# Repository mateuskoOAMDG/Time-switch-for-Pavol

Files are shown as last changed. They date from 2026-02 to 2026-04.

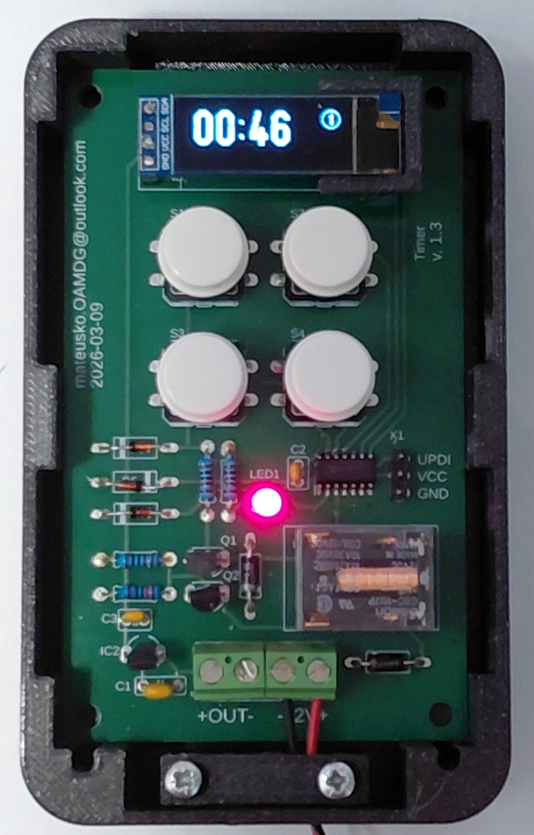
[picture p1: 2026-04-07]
images/Timer12V assembled.png

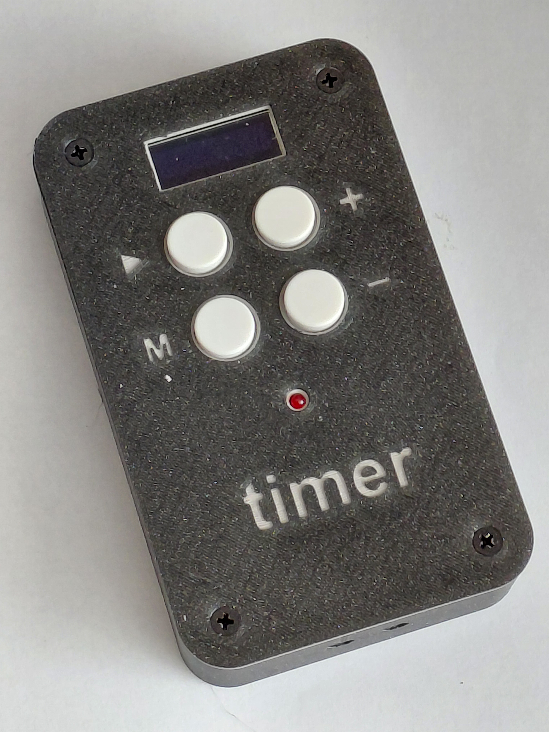
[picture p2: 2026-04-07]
images/Timer-foto1.jpg

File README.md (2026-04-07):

# Timer12V

Simple  timer switch for cars. Switches on the power supply to the heated mat for a set time. The time can be set and stored in one of four memory slots. It is controlled by four buttons and has an OLED display.

For details, see the Wiki (in Slovak) https://github.com/mateuskoOAMDG/Time-switch-for-Pavol/wiki





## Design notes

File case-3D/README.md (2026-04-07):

# List of files for 3D printing
This folder contains all the files for printing the box for the Timer
- 1x **case-top.stl** : The top part of the box should be printed in two colors. The bottom layers (0.5 mm) is black; the rest is gray PETG. 0.25 mm nozzle
- 1x **case-bottom.stl** : The bottom part of the box, printed in black PETG, 0.4 mm nozzle
- 1x **spacer-for-display.stl** : Spacer pad for the display. It is attached to the PCB.
- 1x **top-cable-holder.stl** : The top part of the cable holder. It is secured with two screws into the plastic.
- 4x **button-spacer.stl** : Fretboard pad. It slides onto the button, and the fretboard is then mounted onto it.

*.f3d files are Fusion360 files. You can edit individual parts before printing.

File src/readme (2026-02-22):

This is a sketch for Arduino. There are two files in the Timer directory: .ino and .h. Both must be downloaded and saved in the Timer sketch folder.

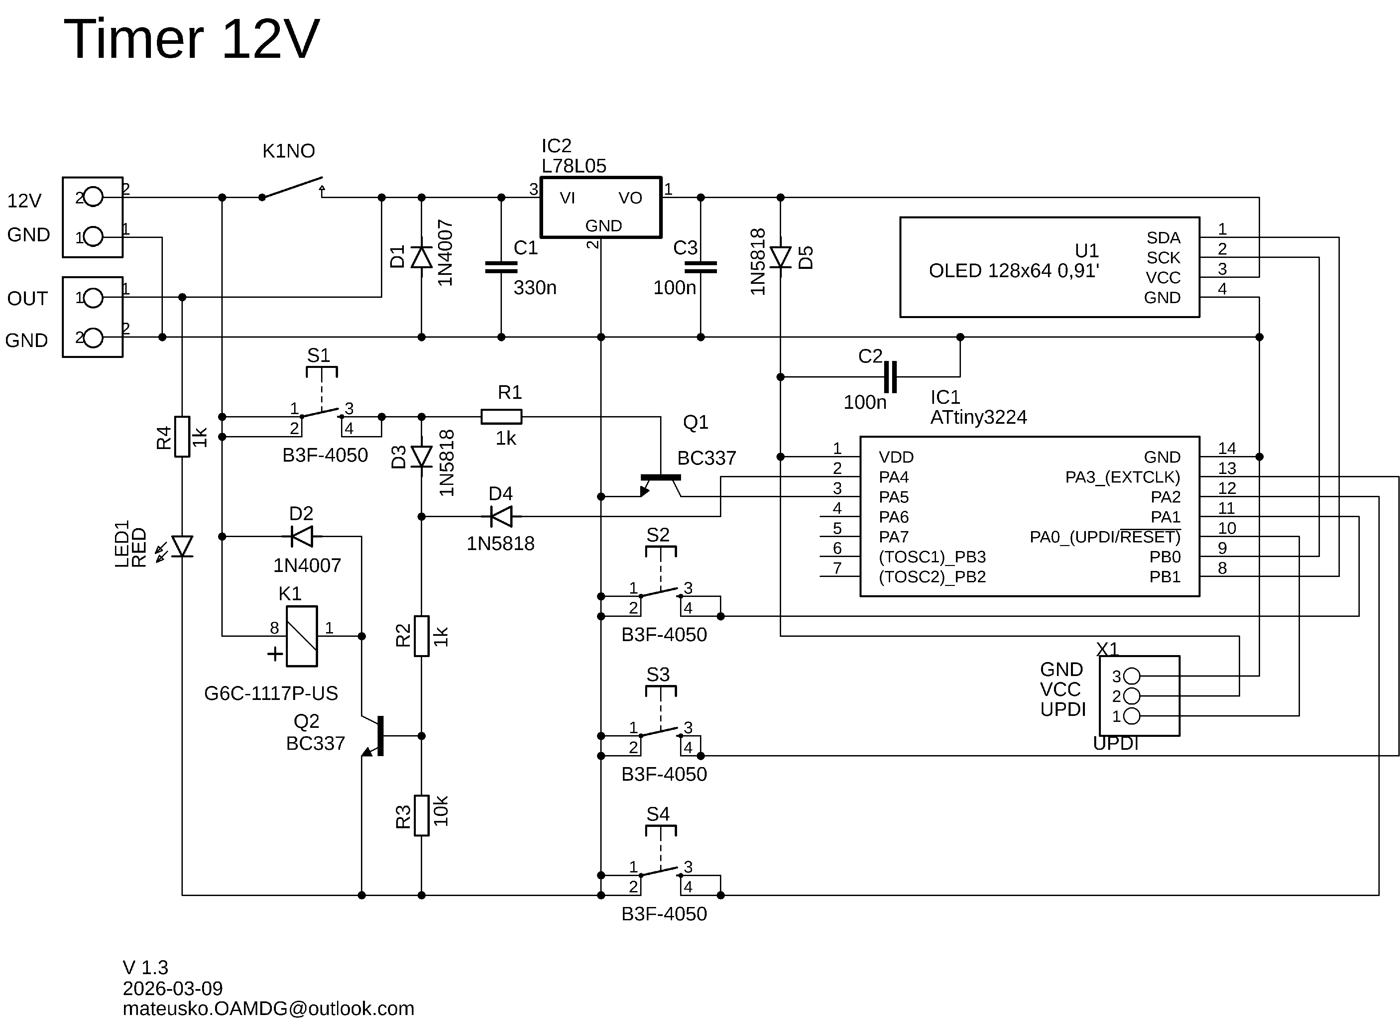
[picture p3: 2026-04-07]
images/Schematics-1.3.png

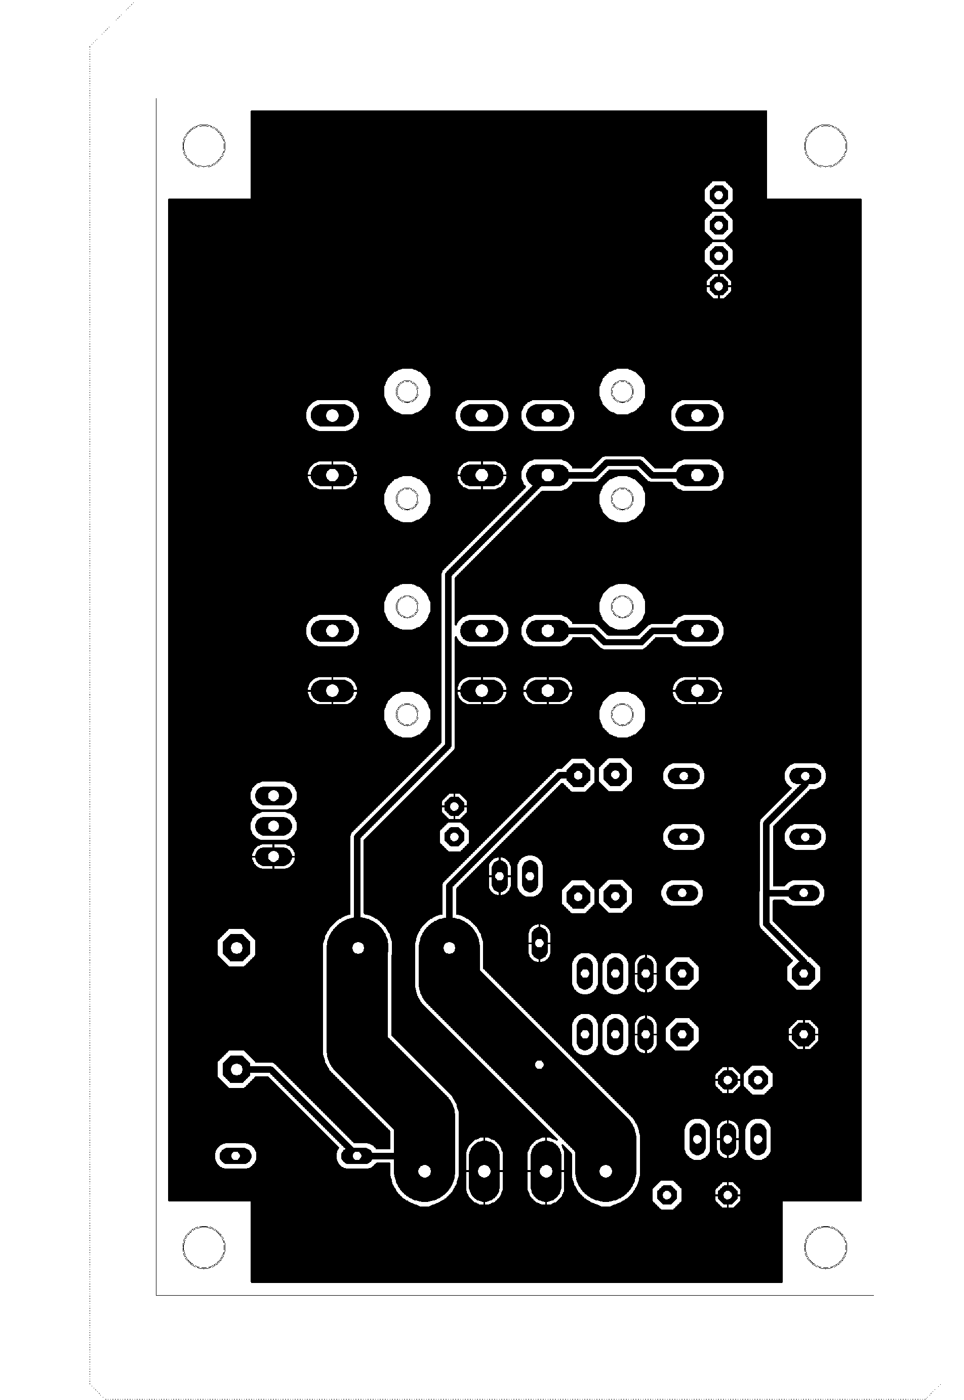
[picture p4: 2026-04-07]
images/PCB-Bottom-1.3.png

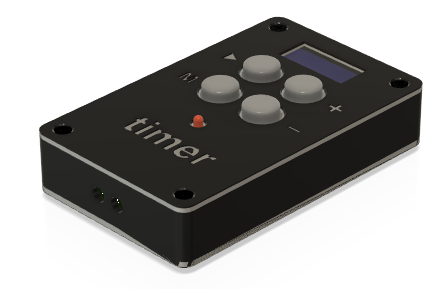
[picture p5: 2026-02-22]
images/case-thumb.png

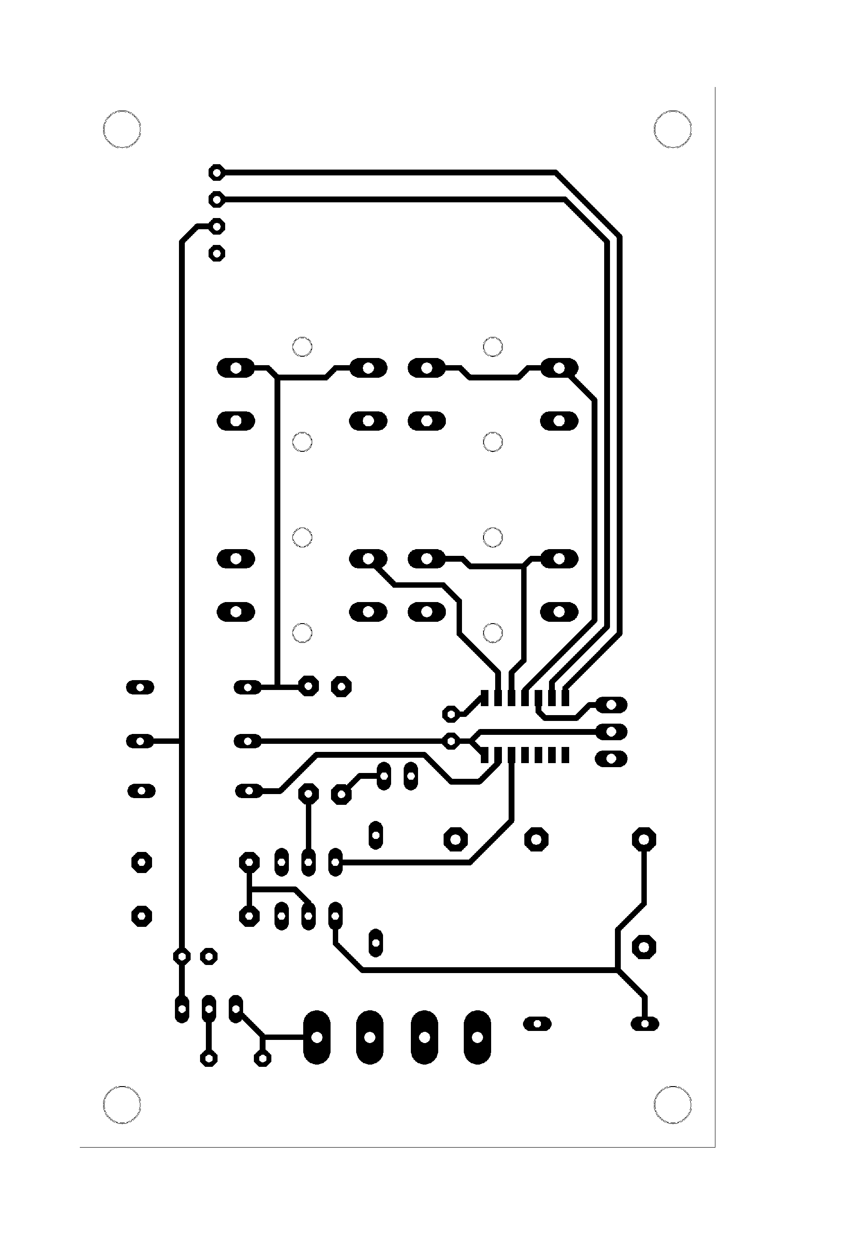
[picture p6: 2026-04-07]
images/PCB-Top-1.3.png

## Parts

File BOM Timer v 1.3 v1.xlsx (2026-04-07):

Name | Timer v 1.3 v1
Exported by | mattheusko
Time of Export | 7. 4. 2026 12:21
Reference Designators | Quantity | Value | Package
 | 1 |  | Board
12V | 1 | TERMINAL_2X_5MM_10A |  | terminal
C1 | 1 | 330n |  | ceramic capacitor
C2, C3 | 2 | 100n |  | ceramic capacitor
D1, D2 | 2 | 1N4007 |  | diode
D3, D4, D5 | 3 | 1N5818 |  | schottky diode
IC1 | 1 | ATtiny3224 | SOIC14 | MCU
IC2 | 1 | L78L05 | TO92 | stabilizer 5V
K1 | 1 | G6C-1117P-US |  | relay
LED1 | 1 | LED red 3mm |  | led
Q1, Q2 | 2 | BC337 | TO92 | transistor NPN
R1, R2, R4 | 3 | 1k | 0207/10 | resistor
R3 | 1 | 10k | 0207/10 | resistor
S1, S2, S3, S4 | 4 | B3F-4050 |  | switch TACT 12mm
U1 | 1 | OLED 128x64 0,91' |  | OLED display I2C, 0,91'
X1 | 1 | UPDI | 1X03 | pin strip; 3 pins
X2 | 1 | TERMINAL_2X_5MM_10A |  | terminal

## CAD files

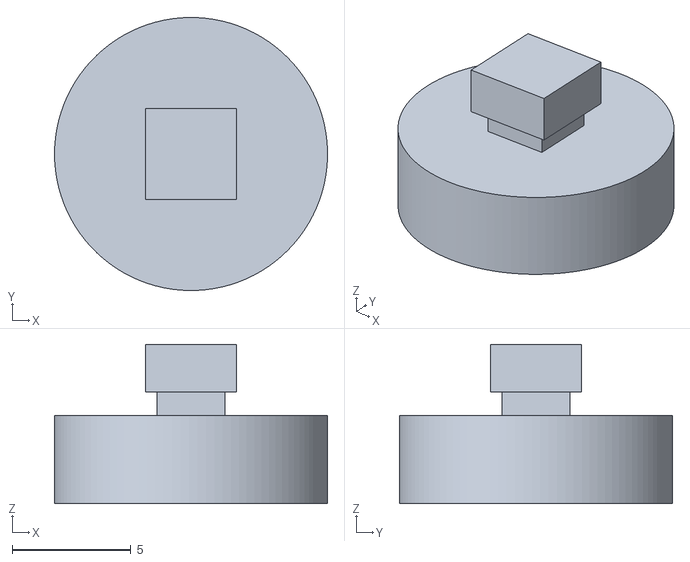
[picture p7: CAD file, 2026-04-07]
case-3D/button-spacer.stl
11.5 x 11.5 x 6.70

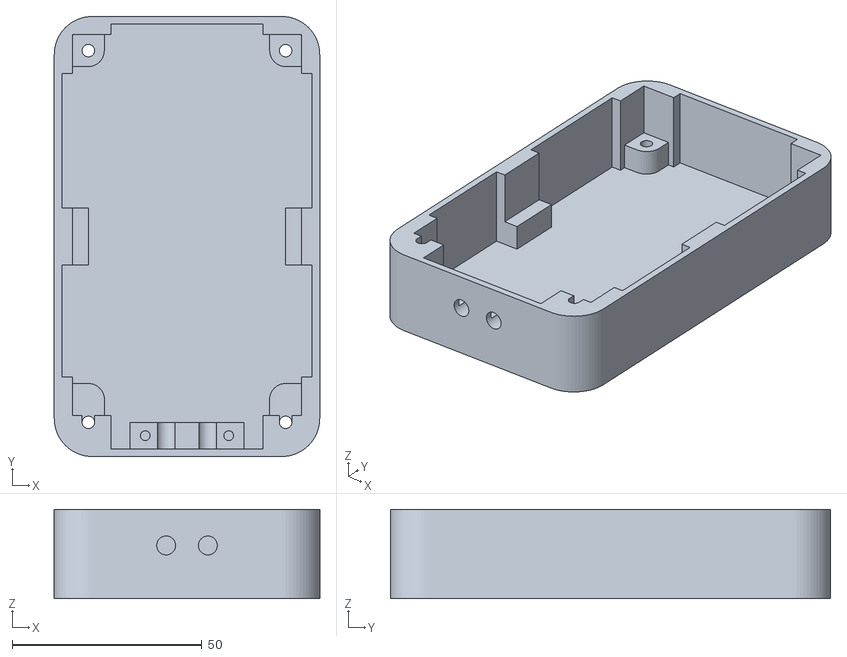
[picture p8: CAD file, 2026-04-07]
case-3D/case-bottom.stl
70.0 x 116.0 x 23.5

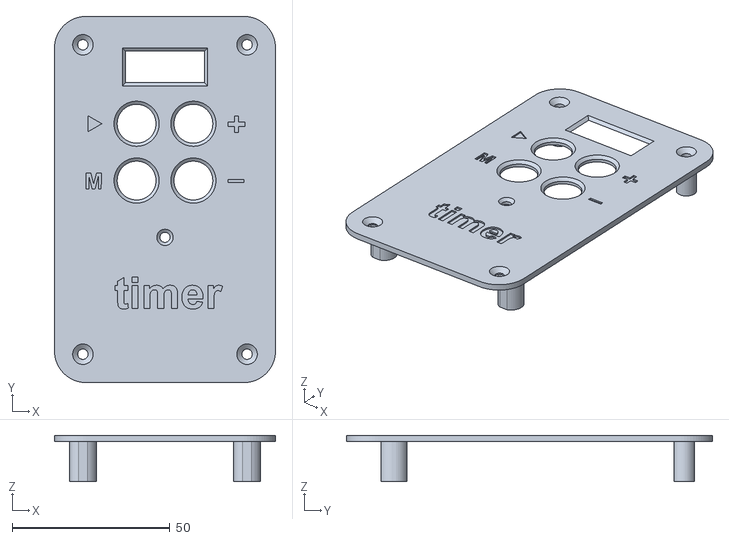
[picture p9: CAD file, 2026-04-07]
case-3D/case-top.stl
70.0 x 116.0 x 14.7

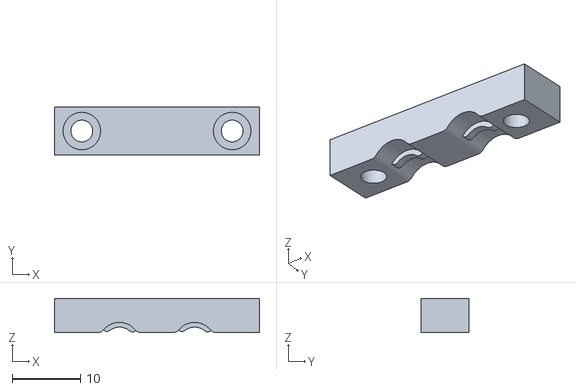
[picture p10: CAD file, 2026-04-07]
case-3D/top-cable-holder.stl
30.0 x 7.00 x 5.00

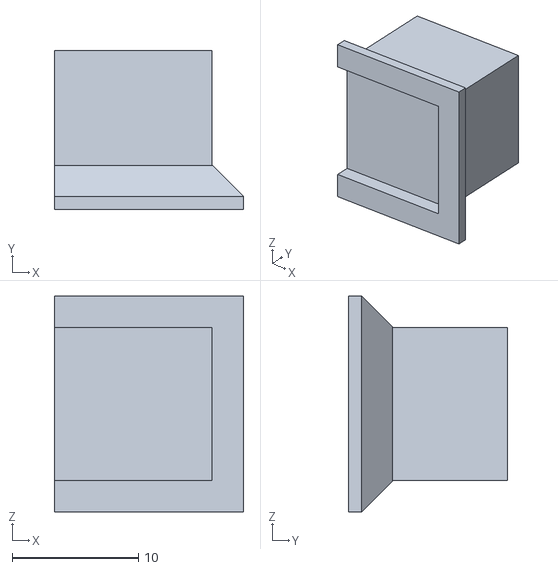
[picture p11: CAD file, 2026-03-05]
case-3D/spacer-for-display.stl
15.0 x 12.6 x 17.1

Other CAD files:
case-3D/ButtonSpacer.f3d
case-3D/Spacer for Display.f3d
case-3D/case-RC1.f3d

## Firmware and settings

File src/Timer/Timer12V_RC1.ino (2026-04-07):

// ------------------------------------------------------------------ //
//                    Timer switch with display                       //
// ------------------------------------------------------------------ //
// version: 1.1.002                                                   //
// PCB: v. 1.3                                                        //
// author : (c) 2026 Martin Janček, mateusko.OAMDG@outlook.com        //
//                                                                    //
// The timer switches on the power supply for the set time.           //
// The times are stored in four presets and can be switched           //
// by briefly pressing the ON button.                                 //
// The time is set using the + and - buttons, and the MODE button     //
// is used to set the interval for adding and subtracting time.       //
// Press and hold the MODE button to save the time to memory.         //
// The active memory number is shown at the top right of the display. //
//                                                                    //
//                                                                    //
// The remaining time is shown on a 128x32 OLED display.              //
// When the time expires, the power relay switches off.               //
// ------------------------------------------------------------------ //
// Controling:                                                        //
//    ON/OFF - pressed LONG  =  ON or OFF                             //
//    PLUS   - pressed SHORT =  time + interval                       //
//    MINUS  - pressed SHORT =  time - interval                       //  
//    ON/OFF - pressed SHORT =  change preset                         //
//    MODE   - pressed SHORT =  change interval                       //
//    MODE   - pressed LONG  =  save current setting to EEPROM        //  
// ------------------------------------------------------------------ //

#include <avr/io.h>
#include <U8g2lib.h>
#include <Wire.h>
#include <RealButton.h>
#include "classes.h"
#include "EEPROM.h"

#define PIN_BUTTON_ON_OFF   PIN_PA5  
#define PIN_BUTTON_PLUS     PIN_PA1
#define PIN_BUTTON_MINUS    PIN_PA2
#define PIN_BUTTON_MODE     PIN_PA3
#define PIN_SUPPLY          PIN_PA4
#define PIN_LED1            PIN_PA6

#define CLOCK_FREEZE_TIME 3 // [s]
#define SECURE_START_TIME 2000 // [ms]

// Dimesions of SettingsArray-s
#define ITEMS_OF_PRESETTIMES 4
#define ITEMS_OF_INTERVALS   2

// Preset TIMEs (see setup)
SettingsArray<int, ITEMS_OF_PRESETTIMES> presetTimes; // [s] objekt poľa s položkami typu unsigned long a size = ITEMS_OF_PRESETTIMES

// Preset intervals (see setup)
SettingsArray<int, ITEMS_OF_INTERVALS> intervals; // [s] objekt poľa s položkami typu int a size = 2

// Display Instantion
U8G2_SSD1306_128X32_UNIVISION_F_HW_I2C  u8g2(U8G2_R0, U8X8_PIN_NONE); // display SSD1306_128X32

// Hardware Buttons Instantions
RealButton buttonOn(PIN_BUTTON_ON_OFF);      // tlačidlo
RealButton buttonPlus(PIN_BUTTON_PLUS);         // tlačidlo
RealButton buttonMinus(PIN_BUTTON_MINUS);       // tlačidlo
RealButton buttonMode(PIN_BUTTON_MODE);         // tlačidlo

// LED Instantion
Led led1(PIN_LED1, HIGH, LOW);

// Main power supply relay Instantion
PowerTimer pt(PIN_SUPPLY);

// Display

// display callbacks
int getTimeCB() {
  return pt.getTime();
}

int getIndexCB() {
  return presetTimes.currentIndex();
}

int getIntervalCB() {
  return intervals.current();
}
 
Display display(&getTimeCB, &getIndexCB, &getIntervalCB);

// Auxiliary
unsigned long timer; // pomocný časovač
bool button_ready = false; // pomocný status tlačidla ON


// EEPROM CRC
unsigned long crcCompute(int length) {
  const unsigned long crc_table[16] = {
      0x00000000, 0x1db71064, 0x3b6e20c8, 0x26d930ac,
      0x76dc4190, 0x6b6b51f4, 0x4db26158, 0x5005713c,
      0xedb88320, 0xf00f9344, 0xd6d6a3e8, 0xcb61b38c,
      0x9b64c2b0, 0x86d3d2d4, 0xa00ae278, 0xbdbdf21c
    };

    unsigned long crc = ~0L;

    for (int index = 0 ; index < length; ++index) {
      crc = crc_table[(crc ^ EEPROM[index]) & 0x0f] ^ (crc >> 4);
      crc = crc_table[(crc ^ (EEPROM[index] >> 4)) & 0x0f] ^ (crc >> 4);
      crc = ~crc;
    }

    return crc;
}





/// @brief Do EEPROM sa uloží inštancia presetTimes a CRC
void saveToEEPROM() {
  presetTimes.setCurrent(pt.getTime());
  EEPROM.put(0, presetTimes);
  EEPROM.put(sizeof(presetTimes), crcCompute(sizeof(presetTimes))); //crc
}

bool loadFromEEPROM() {
  unsigned long saved_crc;
    
  EEPROM.get(0, presetTimes);
  EEPROM.get(sizeof(presetTimes), saved_crc);
  return saved_crc == crcCompute(sizeof(presetTimes)); //crc
}



/////// -------------------- S E T U P -------------------- ///////

void setup() {
  // nastav WDT periodu na ~1s (0x8) – protected write
  _PROTECTED_WRITE(WDT.CTRLA, 0x08);
  
  // SECURE OFF power supply relay 
  pinMode(PIN_SUPPLY, OUTPUT);
  digitalWrite(PIN_SUPPLY, LOW);
  
  timer = millis();

  u8g2.begin(); // inicializacia grafiky
  
  // Inicializacia presetTimes [s]
  if (!loadFromEEPROM()) {
    presetTimes[0] = 60ul; // 5min
    presetTimes[1] = 300ul; // 10min
    presetTimes[2] = 600ul; // 20 min
    presetTimes[3] = 1800ul; // 30 min
    presetTimes.setIndex(0);

    display.printText("Er EPR"); // EEPROM Read Error
    display.freeze(2000);
    display.doFreeze();
  }
  
  // Inicializacia intervals  [min] (time Plus/Minus interval)
  intervals[0] = 1; // 1 min
  intervals[1] = 5; // 5 min

  // inicializacia tlacidiel
  buttonOn.start();
  buttonPlus.start();
  buttonMinus.start();
  buttonMode.start();
  buttonMode.longTime = 2000ul; 

  led1.blink(200);

  if(millis() - timer < SECURE_START_TIME) delay_ds(1);

  // SECURE START
  pt.start(presetTimes.current()); 
  pt.freeze(5);
  // 
}


/////// -------------------- L O O P -------------------- ///////

void loop() {
  
  // Get and handle event

  if (!buttonOn.pressed() && !button_ready) {
      button_ready = true;
      buttonOn.start();
  }

// NEXT_PRESET 
  if (/*buttonOn.pressed() && buttonMode.onPress() || */ buttonOn.onClick()) {
    
    button_ready = false;
   
    presetTimes.next(true); // cyclic mode
    pt.start(presetTimes.current()); // start for current preset time
    pt.freeze(5);
    //display.freeze(2000);
    display.printTimeScreen();
    
  }

// RELAY OFF   
  else if (buttonOn.onLong() && button_ready) {
    
    display.printText("OFF");
    display.freeze(2000);
    pt.off();
  }

// TIME PLUS
  else if (buttonPlus.onPress()) {
    
    int interval = intervals.current() * 60;
    int t = pt.getTime();
    t = (t / interval + 1) * interval;

    if (t <  90 * 60) pt.start(t); 
    display.printTimeScreen(); 
    pt.freeze(5); 
  }

// TIME MINUS
  else if (buttonMinus.onPress()) {
    
     int interval = intervals.current() * 60;
    int t = pt.getTime();
    t = ((t - 1) / interval) * interval;
    if (t > 0) pt.start(t);
    display.printTimeScreen();
    pt.freeze(5);
  }

// CHANGE INTERVAL
  else if (buttonMode.onClick() && !buttonOn.pressed()) {
    
    intervals.next(true);
    display.freeze(2000);
    display.printInterval();
    pt.freeze(5);
  }

// SAVE TO EEPROM
  else if(buttonMode.onLong()) {
    
    saveToEEPROM();
    display.printText("SAVED");
    pt.freeze(5);
    display.freeze(2000);
  }

  // Update Buttons 
  buttonOn.update();
  buttonPlus.update();
  buttonMinus.update();
  buttonMode.update();

  // LED update
  led1.update();

  // Update supply power relay
  pt.update();

  // Display update
  display.update();

  feedWatchdog();
}

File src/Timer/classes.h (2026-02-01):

/**
 * @file classes.h
 * @author Martin Janček, mateusko.OAMDG@outlook.com 
 * @brief class definitions for sketch CasovySpinac.ino
 * @version 0.1
 * @date 2026-01-18
 * 
 * @copyright Copyright (c) 2026 Martin Janček
 * 
 */

#include <stdint.h>
#include <Arduino.h>
#include <U8g2lib.h>

#define DISPLAY_UPDATE_TIME 200

extern U8G2_SSD1306_128X32_UNIVISION_F_HW_I2C  u8g2;

using Callback = int (*)();

// caka ds x 100ms, resetuje watchdog
void delay_ds(unsigned int ds) {
    for (unsigned int i = 0; i < ds; i++) {
    delay(100);
    __asm__ __volatile__("wdr"); // feed watchdog
  }
}

void feedWatchdog() {
    __asm__ __volatile__("wdr");
}

/// @brief States for PowerTimer
enum class TimerState : uint8_t {
  Start, Pause, Off
};

/// @brief states for Led
enum class LedState : uint8_t {
  Off, On, Blink
};

// --------------- C L A S S    L E D ------------------ //

class Led {
  public:
    Led(int pin, int onState = HIGH, int initialState = LOW) : pin(pin), onState(onState) {
        pinMode(pin, OUTPUT);
        digitalWrite(pin, initialState);
        isShining = onState == initialState;
        state = isShining ? LedState::On : LedState::Off;
    };

    void on() {
      isShining = true;
      digitalWrite(pin, onState);
      state = LedState::On;
    }

    void off() {
      isShining = false;
      digitalWrite(pin, onState == HIGH ? LOW : HIGH);
      state = LedState::Off;
    }
    
    void blink(unsigned long interval) {
      blinkInterval = interval;
      timer = millis();
      on();
      state = LedState::Blink;
    }

    void update() {
      if (state == LedState::Blink) {
        if (millis() - timer > blinkInterval) {
          timer = millis();
          if (isShining) off(); else on();
          state = LedState::Blink;
        }
      }
    }


  private:
    int pin;
    int onState;
    LedState state;
    bool isShining;
    unsigned long blinkInterval;
    unsigned long timer;
  
};

// --------------- C L A S S    SettingsArray ------------------ //

/// @brief Staticke pole. Typ položky T. Veľkosť pevná SIZE.
///        Má jednu predvolenú položku (index) 
/// @tparam T 
/// @tparam SIZE 
template <typename T, int SIZE>
class SettingsArray
{
    T data[SIZE]{};
    int index = 0;

public:
    int currentIndex() const { return index; }

    bool setIndex(int i)
    {
        if (i < 0 || i >= SIZE) return false;
        index = i;
        return true;
    }

    T& current() { return data[index]; }

    const T& current() const { return data[index]; }

    void setCurrent(const T& v) { data[index] = v; } // alebo použiješ current() = v;

    bool next(bool cyclic = false)
    {
        if (index + 1 >= SIZE) 
            if (cyclic) {
                index = 0;
                return true;
            }
            else {
                return false;
            }
        else {
            ++index;
            return true;
        }
    }

    bool prev(bool cyclic = false)
    {
        if (index - 1 < 0) 
            if (cyclic) {
                index = SIZE - 1;
                return true;
            }
            else {
                return false;
            }
        else {    
            --index;
            return true;
        }
    }

    T& operator[](int i) { return data[i]; }

    const T& operator[](int i) const {  return data[i]; }
};

// --------------- C L A S S    PowerTimer ------------------ //

/// @brief 
class PowerTimer {
    public:
        
        PowerTimer(int pin, bool logic = true) : pin(pin), logic(logic) {
            pinMode(pin, OUTPUT);
            digitalWrite(pin, logic ? LOW : HIGH); // power OFF
            time = 0;
            timer = 0;
            //freeze_timer = 0;
        }
        
        void start(int time) {
            this->time = time;
            timer = millis();
            digitalWrite(pin, logic ? HIGH : LOW); // power ON
        }


        void off() {
            while(1) {
                digitalWrite(pin, logic ? LOW : HIGH); // power OFF
                __asm__ __volatile__("wdr"); // feed watchdog (secure OFF)
            }
        }
        
        int getTime() { return time;}
        
        void freeze(int time) {
            freeze_time = time;
        }

        void update() {
            if (time <= 0) off();  // time's up, turn off 

            if (millis() - timer >= 1000ul) { // coundown timer "time" -1s
                timer = millis();
                if (freeze_time > 0) {
                    freeze_time --;
                } 
                else {
                    time--;
                }
            }
        }
        
    private:
        int pin; // I/O pin
        bool logic; // true = normal login ON=HIGH, OFF=LOW; false = on the contrary
        int time;  // countdown timer [s]

       
        unsigned long timer; // auxiliary timer
        int freeze_time; // countdown freeze timer

};
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

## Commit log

2026-02-22 Create Timer
2026-02-22 Add initial readme for Arduino sketch
2026-04-07 Update README.md with 3D printing file details
    Added detailed descriptions for 3D printing files.
2026-04-07 Rename project to Timer12V and update description
    Updated project name and description in README.
